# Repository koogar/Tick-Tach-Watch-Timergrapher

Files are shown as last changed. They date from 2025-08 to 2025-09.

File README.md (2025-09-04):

## Tick-Tach: A DIY Timegrapher for Watch Enthusiasts - TallmanLabs 2025

  Mechanical watches may seem timeless, but keeping them accurate requires precise adjustment. That’s where a timegrapher comes in. Traditionally a tool for professional watchmakers, a timegrapher measures the tiny variations in a watch’s ticking to reveal how well its movement is performing.

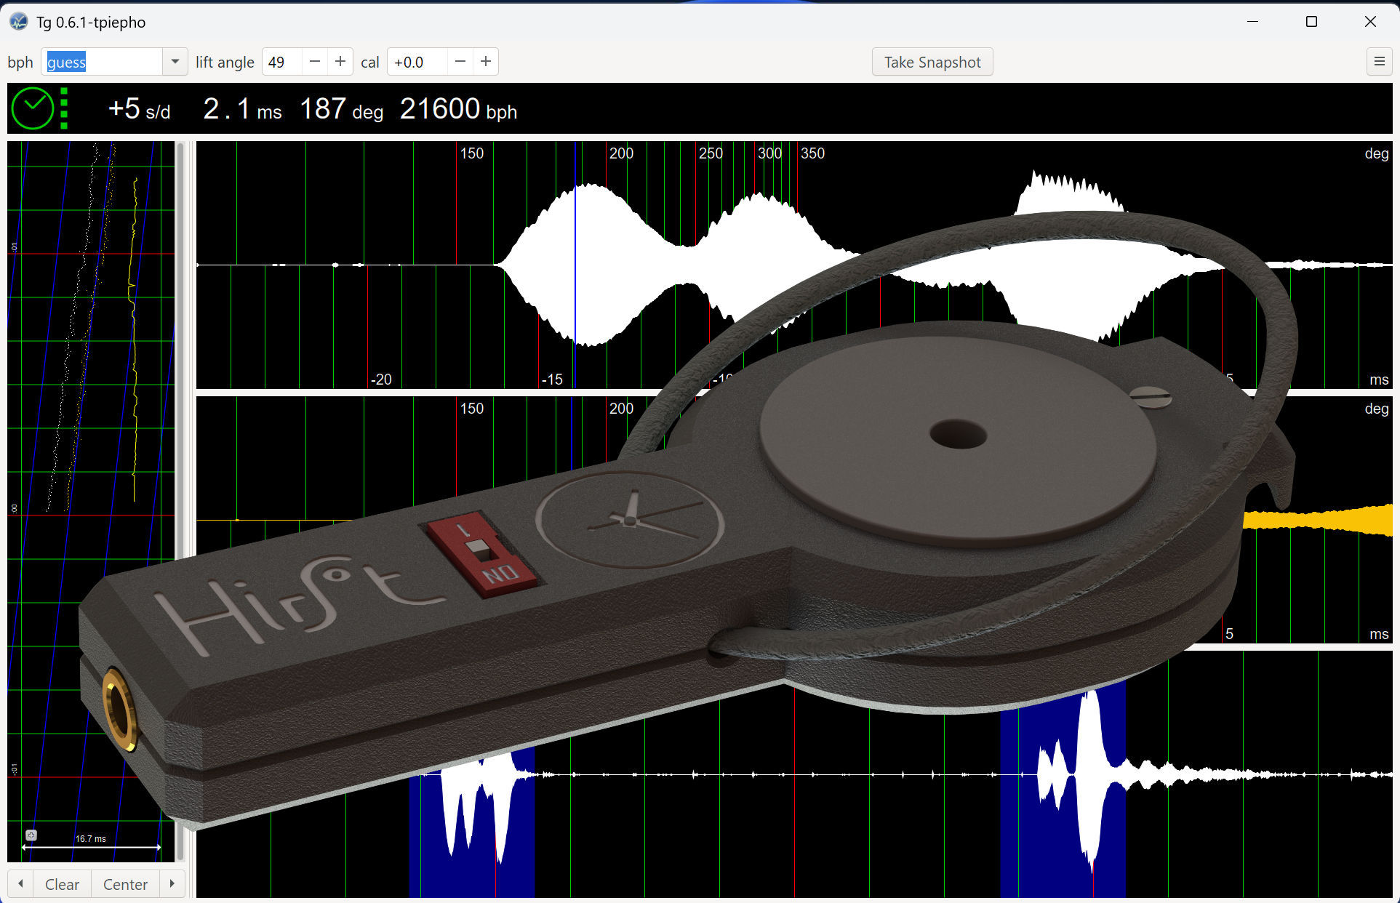
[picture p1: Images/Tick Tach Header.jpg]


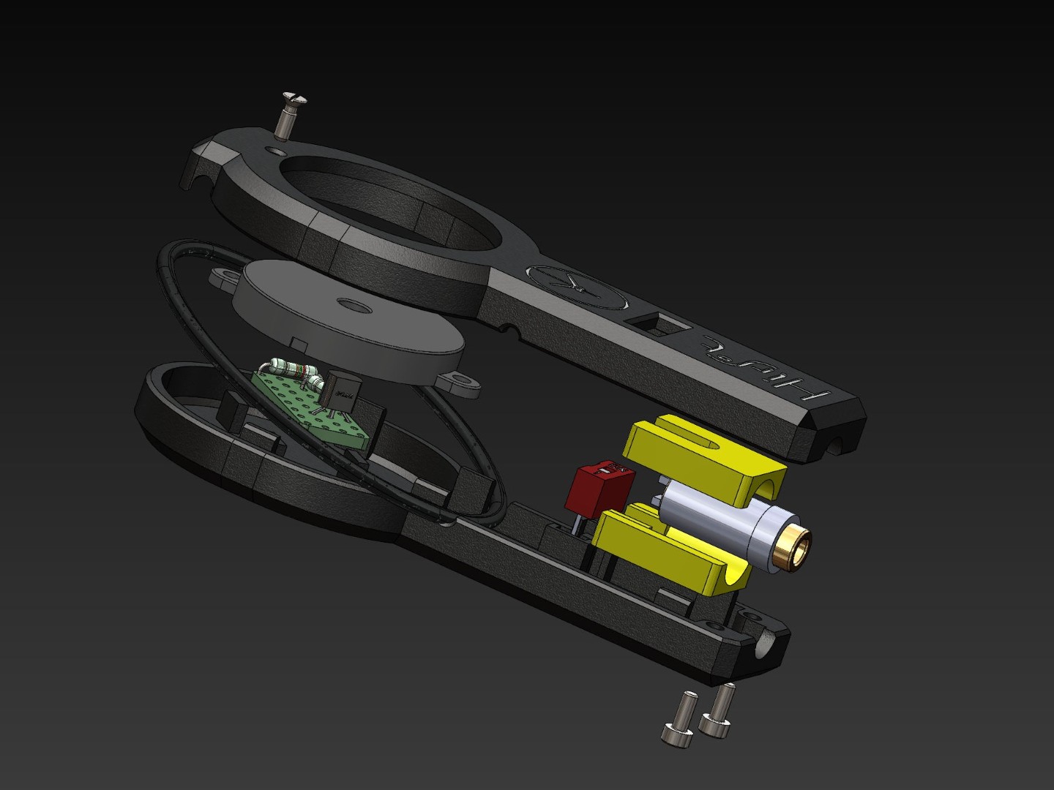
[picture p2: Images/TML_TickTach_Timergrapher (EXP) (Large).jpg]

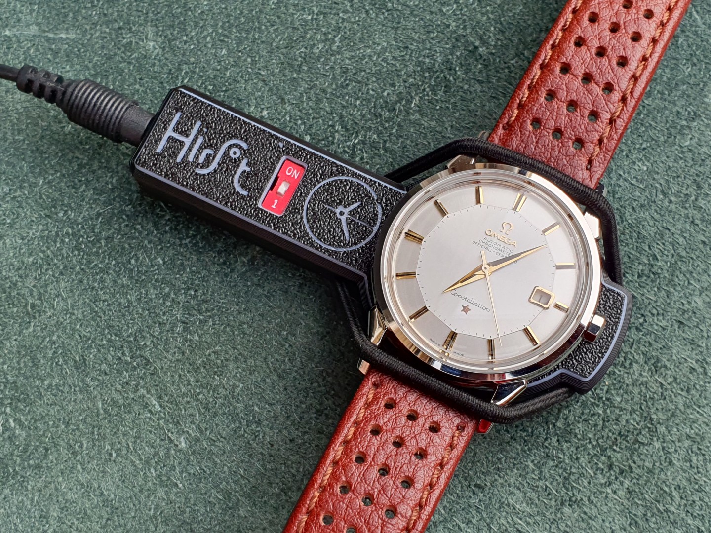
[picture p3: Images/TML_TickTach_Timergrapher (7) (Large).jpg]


## What a Timegrapher Does

At its core, a timegrapher listens to the tick-tock of a mechanical watch and turns that sound into data. The key readings are:

  * Rate – how many seconds the watch gains or loses per day.

  * Amplitude – the swing of the balance wheel, an indicator of movement power.

  * Beat Error – how evenly spaced the tick and tock are, showing whether the balance is centred.

  Together, these measurements tell whether a watch is healthy, in need of regulation, or due for service.

https://github.com/user-attachments/assets/4d9fce35-94cd-408c-842e-20433776a29b

## The Tick-Tach Approach

  Tick-Tach is a DIY project that recreates the essential functions of a timegrapher using simple, accessible parts. Instead of an expensive acoustic sensor, Tick-Tach relies on a 30mm piezo electric microphone to detect the faint vibrations of a watch. The weak signal is amplified with a transistor-based preamp before being processed into meaningful timing data.

  Unlike commercial probes, Tick-Tach’s electronics are housed in a custom 3D-printed enclosure. The case (shown above) is designed with a circular recess for the watch to rest on, a cavity for the 30mm piezo sensor, a neatly integrated preamp board, and a headphone-style jack for easy connection. A small toggle switch adds convenience. A hair bobble is integrated into the case to retain the watch when rotating, during different position tests.

Tick-Tach is also software compatible, working with the open-source “tg-timer”, "PC Timer Machine" application on PC and the "Watch Accuracy Meter" app on Android. This allows users to visualise live waveforms, track performance, and adjust their watches using the platform they prefer.

## Why It Matters

  For hobbyists, modders, and independent watch repairers, commercial timegraphers can be costly. Tick-Tach lowers the barrier, offering enthusiasts a practical way to check accuracy, regulate their watches, and better understand the mechanics inside. It’s also a rewarding build for anyone into electronics, 3D printing, and horology.

With its smart enclosure and open-source software compatibility, Tick-Tach bridges the gap between professional watchmaking tools and the DIY workshop.

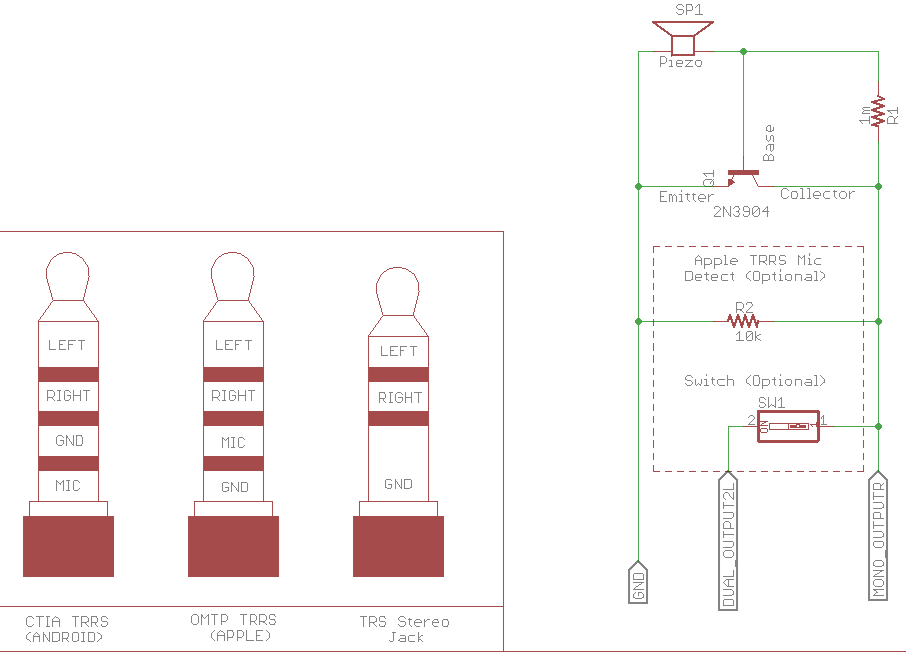
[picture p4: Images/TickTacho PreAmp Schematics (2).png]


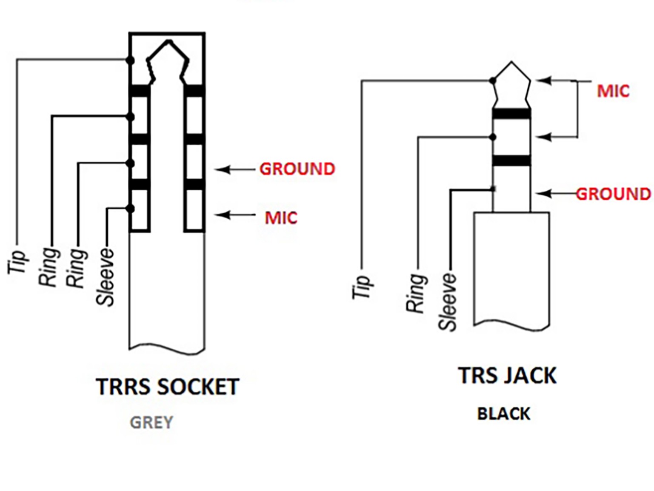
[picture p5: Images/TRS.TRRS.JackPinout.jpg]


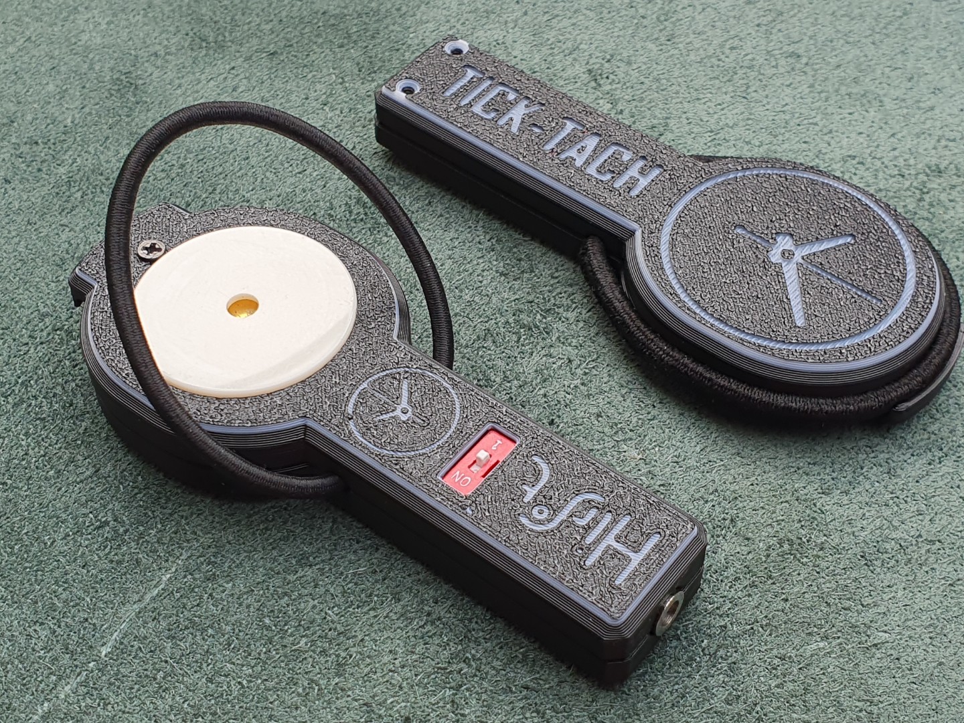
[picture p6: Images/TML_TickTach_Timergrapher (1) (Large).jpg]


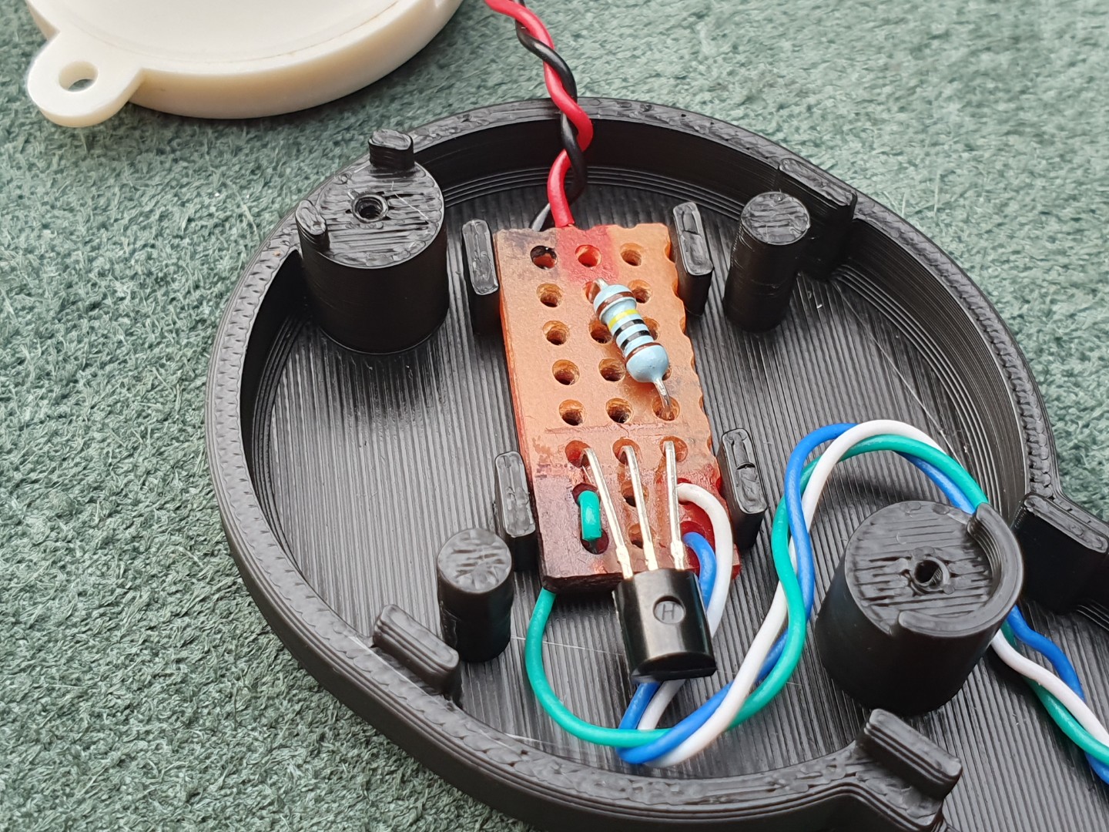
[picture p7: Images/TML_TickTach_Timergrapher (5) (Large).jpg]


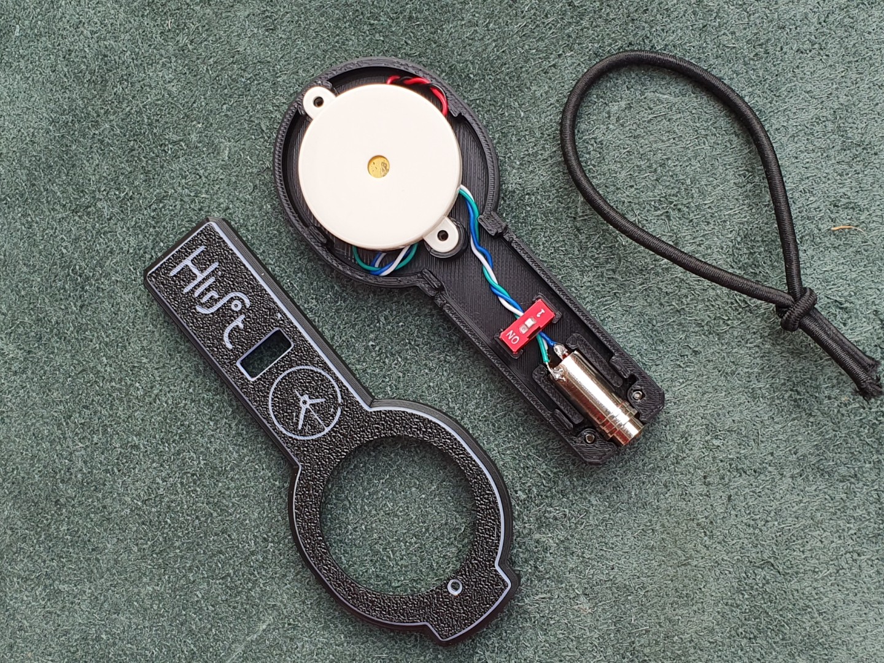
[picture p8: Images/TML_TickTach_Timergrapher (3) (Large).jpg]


## Technical Notes & Tips

* Apple device compatibility: Some iPhones expect a load on the microphone input of the TRRS socket. A 10 kΩ resistor between ground and mic output may be needed to “wake” the input. In some cases, mic and ground may also be reversed on the connector.

* Mono signal: The piezo pickup is mono, but this makes no difference to the timegrapher’s performance, since the software only needs a single channel of clean input. Using a standard TRRS mic/headphones adaptor may present it as dual mono, but in practice the analysis works the same.

* Piezo pickup behaviour: Unlike air microphones, the piezo disc works mainly by sensing vibration transmitted through contact with the watch case. The downside is that piezo sensors are very microphonic — they can pick up knocks, cable movement, or handling noise, so careful placement and housing design help reduce unwanted signals.

## Why Tick-Tach Stands Out

* Affordable yet accurate: Avoids the cost of commercial timegraphers while delivering reliable data.

* Open-source friendly: Works with the tg software on PC and Watch Accuracy Meter on Android for versatile use.

* Maker-centric UX: 3D-printed housing, component-level transparency, and customization potential.

* Educational and empowering: A practical electronics, signal-processing, and horology project that helps build understanding while enabling real diagnostic capability.

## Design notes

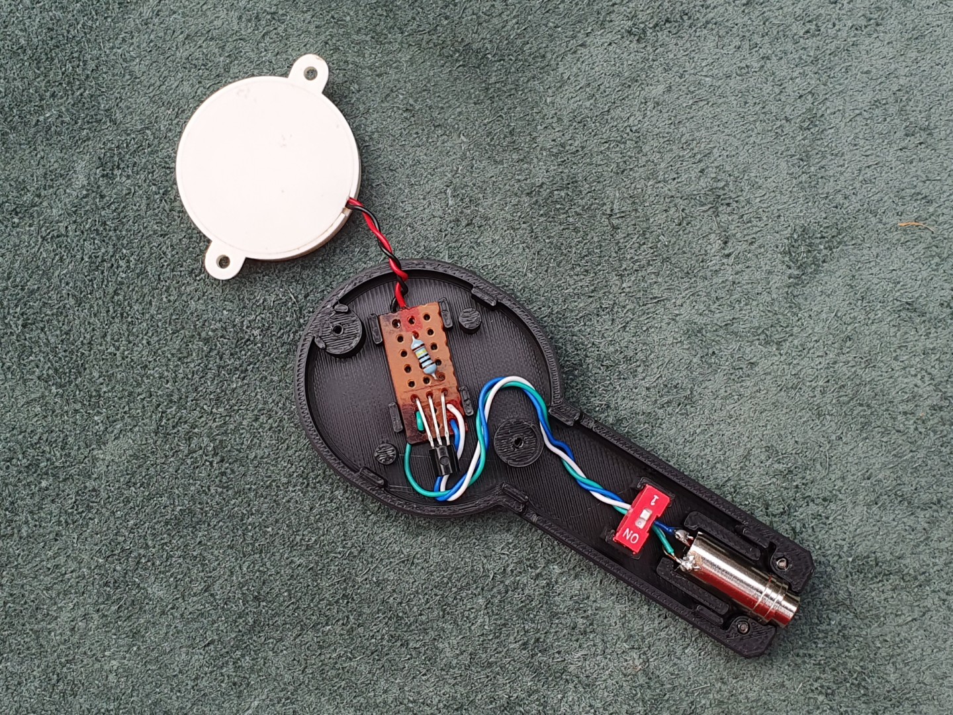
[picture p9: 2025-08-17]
Images/TML_TickTach_Timergrapher (4) (Large).jpg

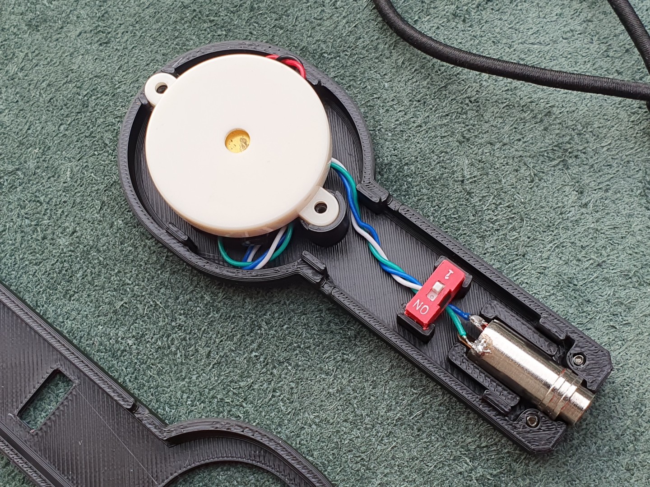
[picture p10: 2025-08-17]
Images/TML_TickTach_Timergrapher (2) (Large).jpg

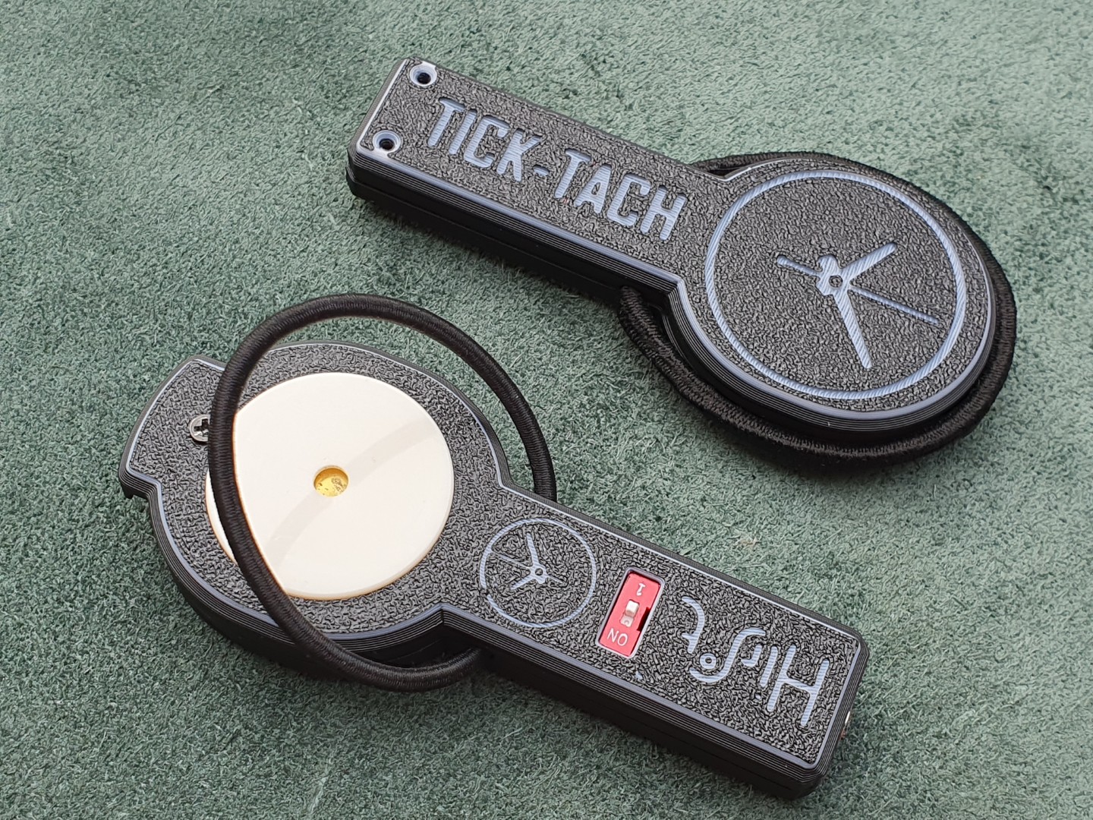
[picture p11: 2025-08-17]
Images/TML_TickTach_Timergrapher (8) (Large).jpg

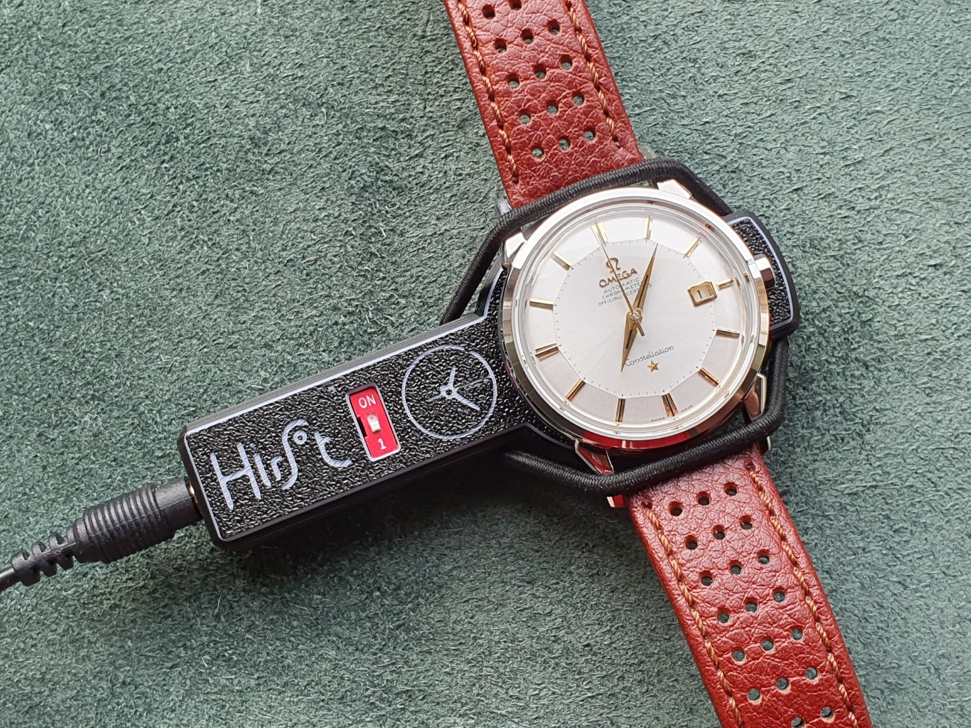
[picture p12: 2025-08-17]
Images/TML_TickTach_Timergrapher (6) (Large).jpg

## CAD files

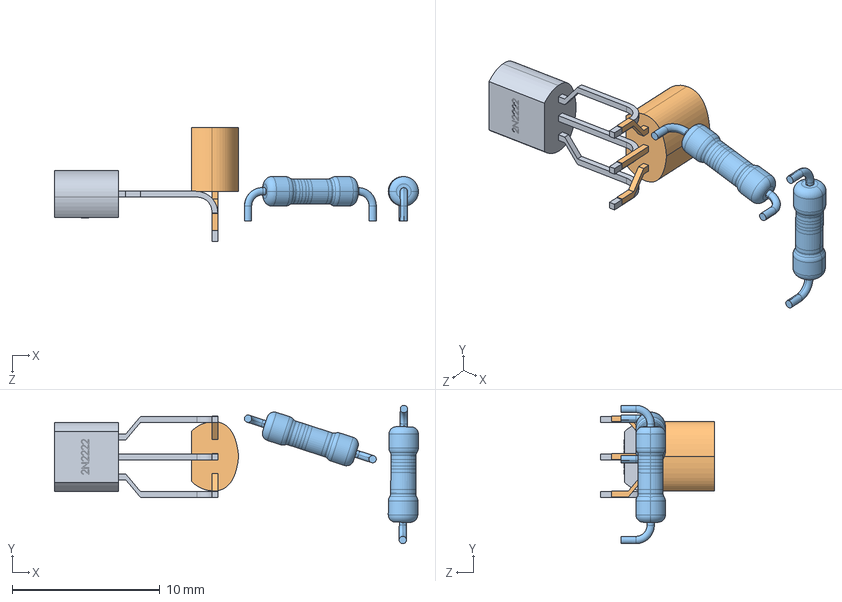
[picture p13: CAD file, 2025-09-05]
Solidworks/TML_TickTacho_Timergraph_Mic_SWModel/TickTach ProtoPCB UPRight.SLDASM
24.6 x 9.36 x 7.71 mm
Resistor x 2
2N2222.step
2N2222 horizontal.step

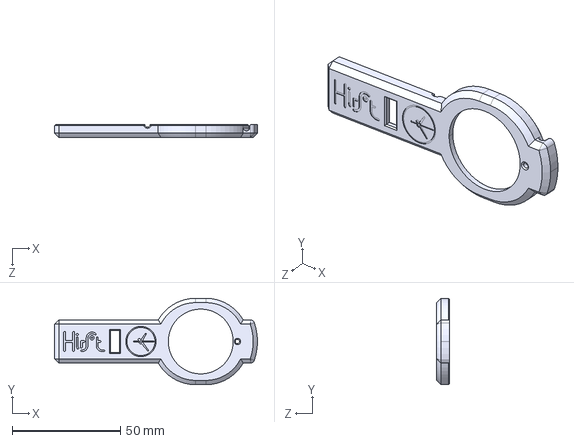
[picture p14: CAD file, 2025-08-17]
3D Print Enclosure/Depreciated/TML_TickTacho_Timergraph_Mic_TopCover v2.STEP
93.9 x 40.0 x 6.00 mm

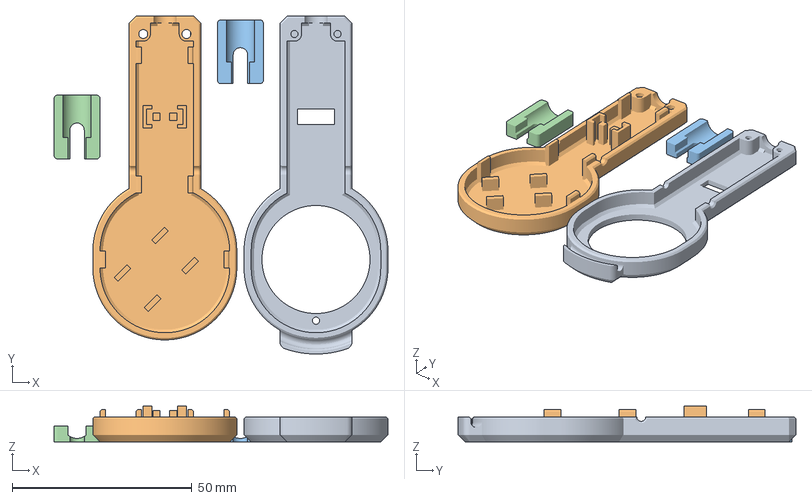
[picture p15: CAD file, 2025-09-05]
Solidworks/TML_TickTacho_Timergraph_Mic_SWModel/Step/TML_TickTacho_Timergraph_Mic_v2.1.3mf
92.8 x 93.9 x 10.0 mm
TML_TickTacho_Timergraph_Mic_TopCover v2.1.STEP
TML_TickTacho_Timergraph_Mic_BottomCover v2.1.STEP
Jack Housing Bottom.STEP
Jack Housing Top.STEP

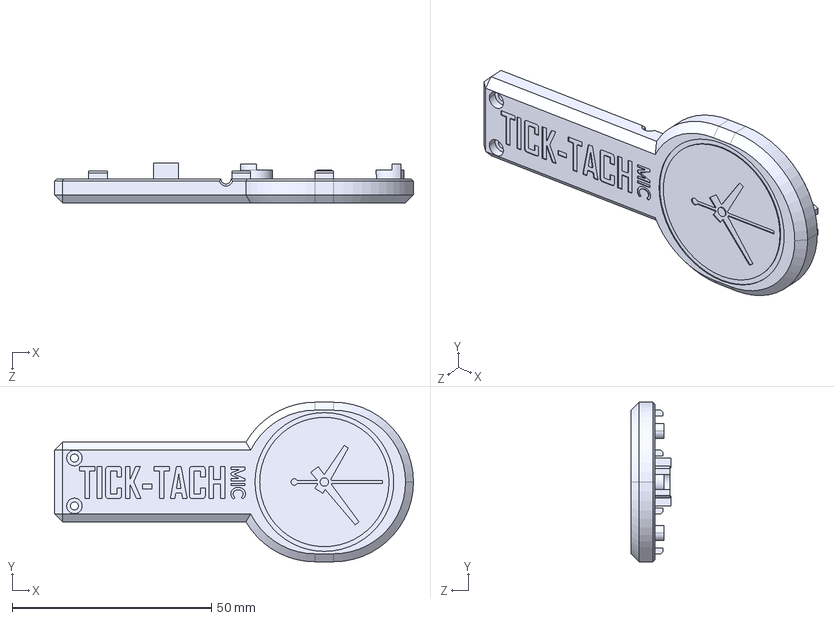
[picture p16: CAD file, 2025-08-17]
3D Print Enclosure/Depreciated/TML_TickTacho_Timergraph_Mic_BottomCover v2.STEP
90.0 x 40.0 x 10.0 mm

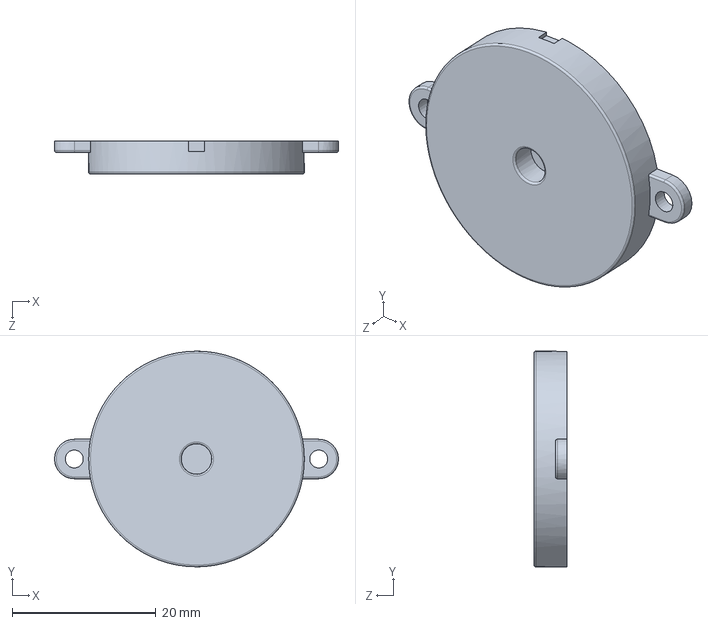
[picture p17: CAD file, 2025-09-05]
Solidworks/TML_TickTacho_Timergraph_Mic_SWModel/30mm Piezo.SLDPRT
39.5 x 30.0 x 4.60 mm

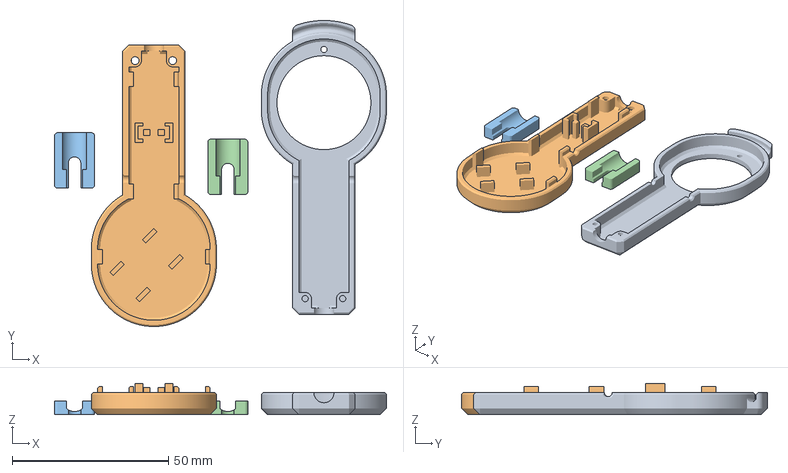
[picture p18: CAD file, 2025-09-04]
Solidworks/TML_TickTacho_Timergraph_Mic_SWModel/Step/TML_TickTacho_Timergraph_Mic_NoSwitch_v2.1.3mf
106.1 x 97.8 x 10.0 mm
TML_TickTacho_Timergraph_Mic_TopCover NoSwitch v2.1.STEP
TML_TickTacho_Timergraph_Mic_BottomCover v2.1.STEP
Jack Housing Bottom.STEP
Jack Housing Top.STEP

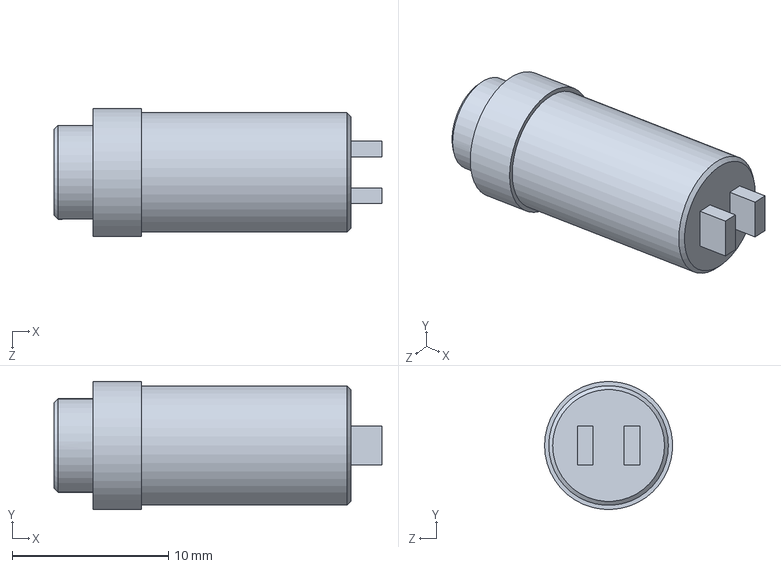
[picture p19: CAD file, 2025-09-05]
Solidworks/TML_TickTacho_Timergraph_Mic_SWModel/Audio Jack.SLDPRT
21.0 x 8.20 x 8.19 mm

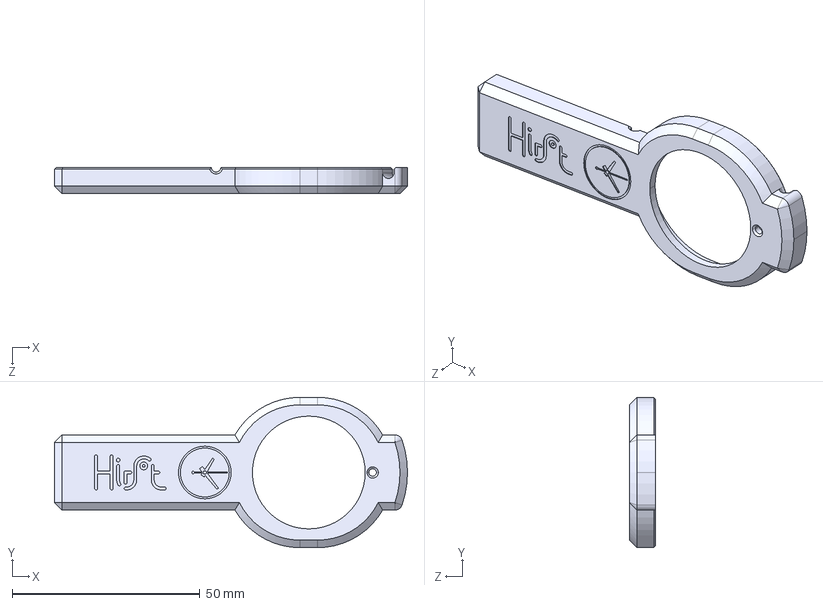
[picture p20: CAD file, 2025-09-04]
Solidworks/TML_TickTacho_Timergraph_Mic_SWModel/Step/TML_TickTacho_Timergraph_Mic_TopCover NoSwitch v2.1.STEP
93.9 x 40.0 x 7.00 mm

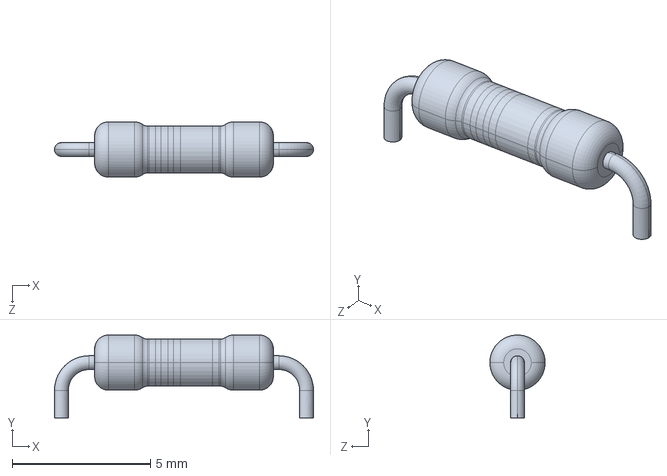
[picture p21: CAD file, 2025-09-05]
Solidworks/TML_TickTacho_Timergraph_Mic_SWModel/Resistor.SLDPRT
9.36 x 3.00 x 2.00 mm

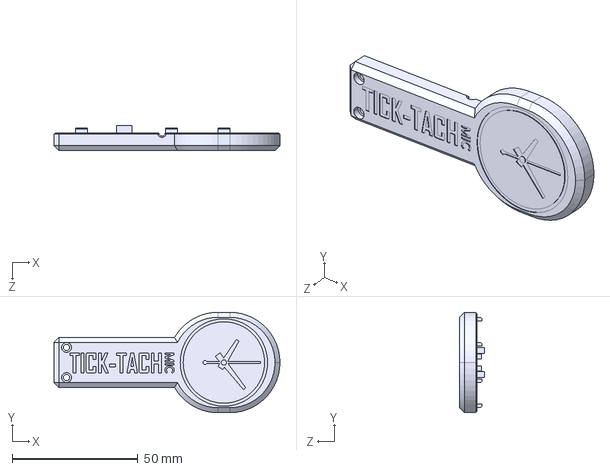
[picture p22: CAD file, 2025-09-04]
Solidworks/TML_TickTacho_Timergraph_Mic_SWModel/Step/TML_TickTacho_Timergraph_Mic_BottomCover v2.1.STEP
90.0 x 40.0 x 10.0 mm

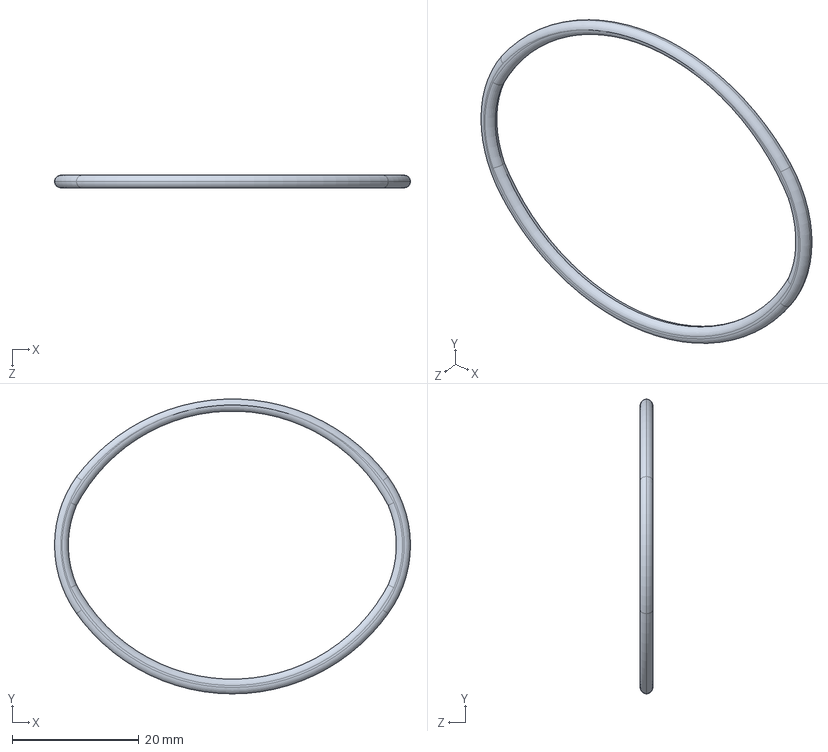
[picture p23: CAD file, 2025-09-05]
Solidworks/TML_TickTacho_Timergraph_Mic_SWModel/Bobble.SLDPRT
56.2 x 46.5 x 2.00 mm

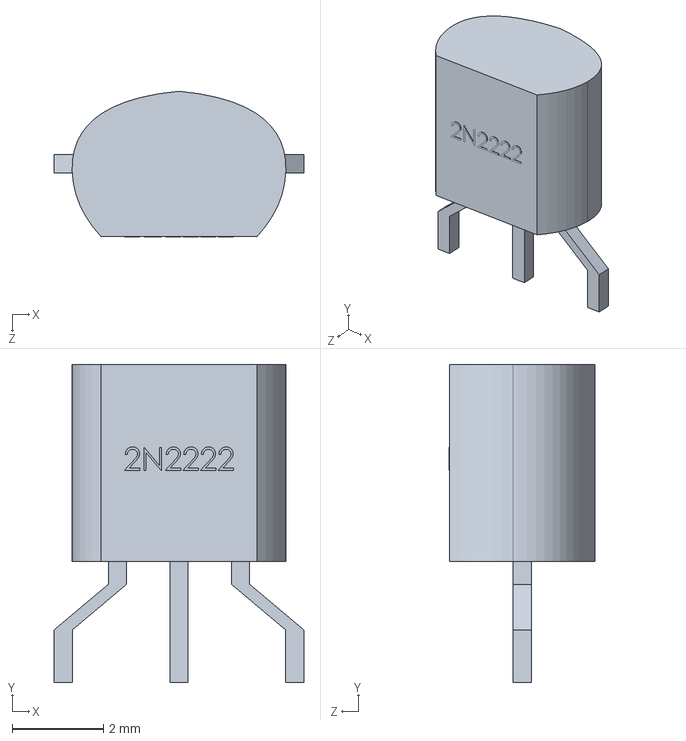
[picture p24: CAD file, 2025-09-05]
Solidworks/TML_TickTacho_Timergraph_Mic_SWModel/2N2222.step.SLDPRT
5.48 x 6.97 x 3.19 mm

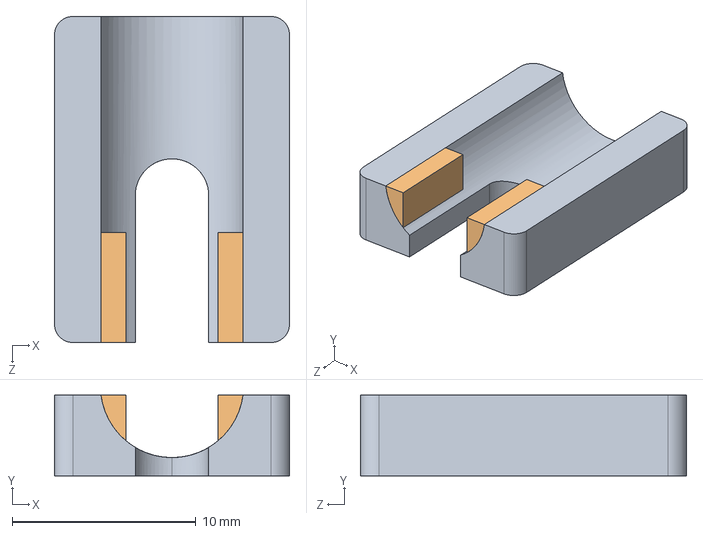
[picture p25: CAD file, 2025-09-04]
Solidworks/TML_TickTacho_Timergraph_Mic_SWModel/Step/Jack Housing Top.STEP
12.8 x 4.40 x 17.8 mm

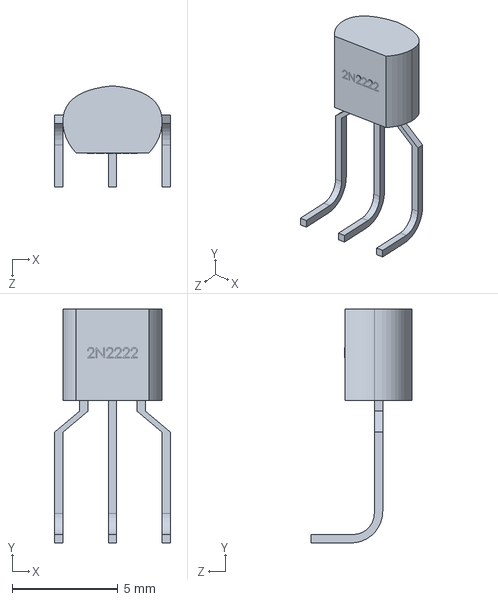
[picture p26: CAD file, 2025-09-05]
Solidworks/TML_TickTacho_Timergraph_Mic_SWModel/2N2222 horizontal.step.SLDPRT
5.48 x 11.1 x 4.79 mm

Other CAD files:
Solidworks/TML_TickTacho_Timergraph_Mic_SWModel/TML_TickTacho_Timergraph_Mic_Bobble_14mm_V2.1.SLDASM
Solidworks/TML_TickTacho_Timergraph_Mic_SWModel/TickTach ProtoPCB Horizontal.SLDASM
Solidworks/TML_TickTacho_Timergraph_Mic_SWModel/Step/TML_TickTacho_Timergraph_Mic_TopCover v2.1.STEP
Solidworks/TML_TickTacho_Timergraph_Mic_SWModel/Step/Jack Housing Bottom.STEP
3D Print Enclosure/Depreciated/STL/TML_TickTacho_Timergraph_Mic_BottomCover v2.STL
3D Print Enclosure/Depreciated/STL/TML_TickTacho_Timergraph_Mic_TopCover v2.STL
3D Print Enclosure/Depreciated/TML_TickTacho_Timergraph_Mic_BottomCover v2.3mf
Solidworks/TML_TickTacho_Timergraph_Mic_SWModel/Dip Switch.SLDPRT
Solidworks/TML_TickTacho_Timergraph_Mic_SWModel/Jack Housing Bottom.SLDPRT
Solidworks/TML_TickTacho_Timergraph_Mic_SWModel/Jack Housing Top.SLDPRT
Solidworks/TML_TickTacho_Timergraph_Mic_SWModel/PCB_50x70_2,54.stp
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

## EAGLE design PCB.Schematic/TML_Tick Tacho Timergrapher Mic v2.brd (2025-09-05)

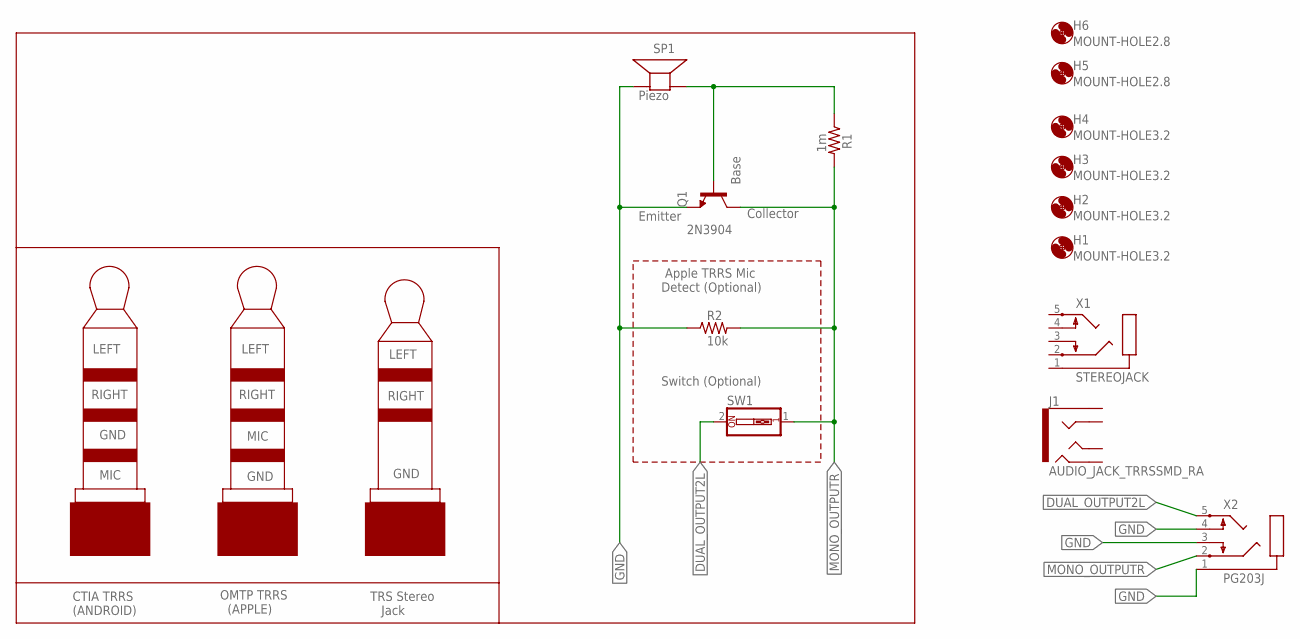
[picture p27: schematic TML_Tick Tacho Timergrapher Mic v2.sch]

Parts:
H1, H2, H3, H4: MOUNT-HOLE3.2; 3,2
H5, H6: MOUNT-HOLE2.8; 2,8
J1: AUDIO_JACK_TRRSSMD_RA; AUDIO_JACK_3.5MM_TRRS_SMD_RA
Q1: 2N3904; TO92
R1: 1m; 0204/7
R2: 10k; 0204/7
SP1: Piezo; AL60P
SW1: SW_DIP-1; EDG-01
X1: STEREOJACK; STX3100
X2: PG203J

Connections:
DUAL_OUTPUT2L: SW1.2, X2.5
GND: Q1.3 (E), R2.1, SP1.1 (+), X2.1, X2.3, X2.4
MONO_OUTPUTR: Q1.1 (C), R1.2, R2.2, SW1.1, X2.2
unnamed: Q1.2 (B), R1.1, SP1.2 (-)

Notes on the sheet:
Emitter
Collector
Base
Piezo
Apple TRRS Mic Detect (Optional)
MIC
GND
RIGHT
LEFT
CTIA TRRS (ANDROID)
OMTP TRRS (APPLE)
TRS Stereo Jack
Switch (Optional)

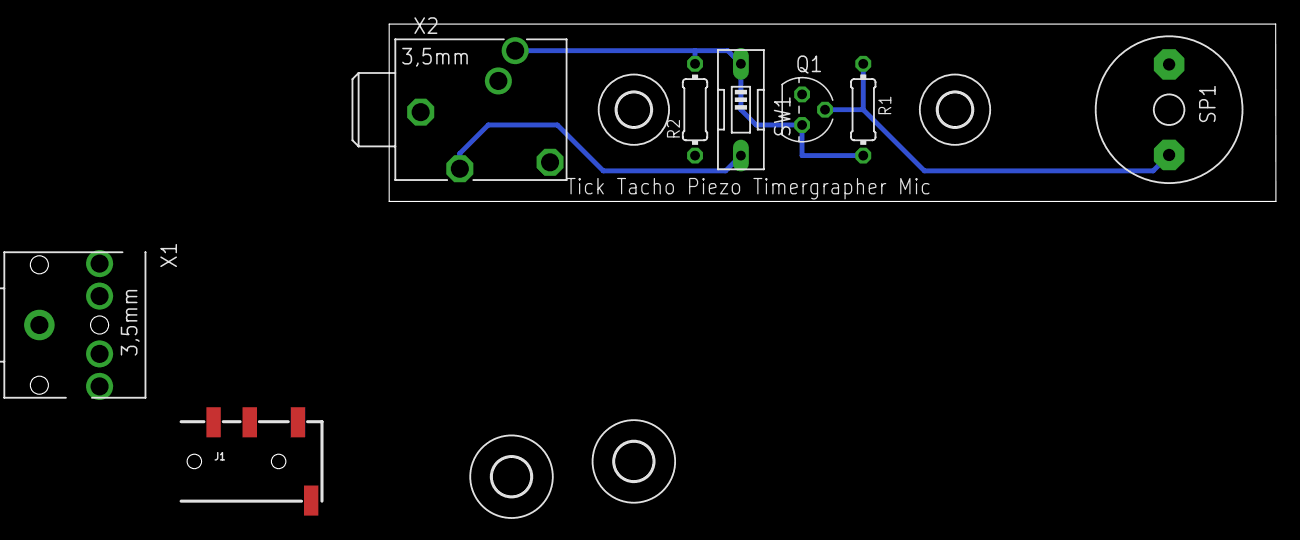
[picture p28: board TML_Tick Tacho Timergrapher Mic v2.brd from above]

Board: 2 copper layers, 73.6 x 14.7 mm, 14 parts (0 on the bottom side), 4 nets.

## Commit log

2025-08-17 upload v2 3dprint
    [TML_TickTacho_Timergraph_Mic_BottomCover v2.3mf, TML_TickTacho_Timergraph_Mic_BottomCover v2.STEP, TML_TickTacho_Timergraph_Mic_TopCover v2.STEP]
2025-08-17 add stl
    [TML_TickTacho_Timergraph_Mic_BottomCover v2.STL, TML_TickTacho_Timergraph_Mic_TopCover v2.STL]
2025-08-17 add dirs
    [TML_TickTacho_Timergraph_Mic_BottomCover v2.STEP, TML_TickTacho_Timergraph_Mic_BottomCover v2.STL, TML_TickTacho_Timergraph_Mic_TopCover v2.STEP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]

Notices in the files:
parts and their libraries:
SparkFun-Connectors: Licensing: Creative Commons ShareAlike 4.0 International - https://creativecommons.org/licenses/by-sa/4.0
